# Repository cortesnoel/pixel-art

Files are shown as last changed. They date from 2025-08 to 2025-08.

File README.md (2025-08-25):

<h1 align="center" color="blue">
  <br>
  Pixel Art
  <br>
</h1>

<h4 align="center">Learn AI and game programming at the edge.</h4>

<p align="center">
  <a href="#key-features">Key Features</a> •
  <a href="#what-is-pixel-art">What is Pixel Art</a> •
  <a href="#why-pixel-art">Why Pixel Art</a> •
  <a href="#how-to-use">How to use</a> •
  <a href="#how-pixel-art-works">How Pixel Art Works</a> •
  <a href="#tutorials">Tutorials</a> •
  <a href="#community-plugins">Community Plugins</a> •
  <a href="#contributions">Contributions</a> •
  <a href="#license">License</a>
</p>

<p align="center">
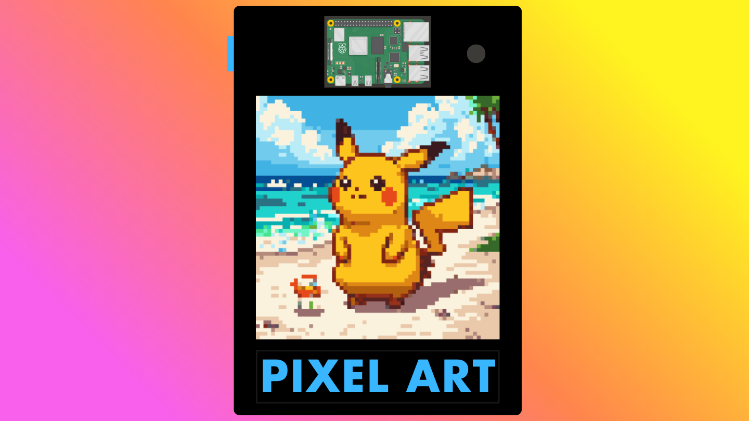
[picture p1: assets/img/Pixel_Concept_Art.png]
Markdownify
  
</p>

## Key Features

### Hardware

- edge platform using Raspberry Pi 4
- base build with opt-in components
- very minimal soldering
- customizable case design

### Software

- extendable through RGB, AI, game plugins
- support for RGB plugin development using [rpi-rgb-led-matrix](https://github.com/hzeller/rpi-rgb-led-matrix)
- support for AI plugin development using [Picovoice](https://picovoice.ai)
- support for game plugin development using [Pygame](https://www.pygame.org/wiki/GettingStarted)
- many plugin examples for RGB, AI, and games, ranging from simple to complex
- flexible plugin architecture so you can:
  - build custom plugins using other libraries or APIs (ex. OpenAI)
  - pair RGB with AI or game plugins in one-to-one, one-to-many, or many-to-many relationships
- built-in support for AI plugin audio and image modalities

## What is Pixel Art?

Pixel Art is a fun edge device for learning AI application and game development.
It provides a friendly environment for developers to create their own apps and games through plugins, then transfer those apps, or even integrate some or all of Pixel Art itself, into their own edge projects.

Pixel Art includes a 64x64 LED screen display, microphone, and optional speaker to support image and audio modalities.
Using Raspberry Pi 4 as it's main compute, it can support game development using smaller footprint libraries like Pygame.
It can also support small AI model inferencing locally or API requests to externally-hosted AI models.

The design is opensource under the [MIT](LICENSE) license so developers can customize Pixel Art towards their own learning goals by adding new hardware components, modifying the 3D prints, or creating custom software plugins.

## Why Pixel Art?

Studying various tech over the past several years, I found that developing on a personal or cloud compute often dulls the experience of learning new tech.
In many ways I felt disconnected from the tech I was learning.
The more I learned, the more it all transformed into an obscure blob within a "projects" or "study" folder.

I wanted a platform that made learning more engaging and personalized towards my own learning goals.

This is why I created Pixel Art, for software developers like me who also want to see their learning experience and apps come to life.
A complete learning platform with an open design that can be personalized towards individual learning goals and app deployments.

For education, this means a fun and refreshing development platform that can adapt to new projects and explorations.

If you're also looking to personalize your learning experience, further connect with the apps you're developing, or just really like pixel art, give it a try!

## How to use?

To use Pixel art you'll need to build the device, install the main software, then run existing plugins or create your own.

### Build Device

Visit [hardware](hardware) for a complete hardware build guide.

### Installation and Setup

Now that you have at least a base build of Pixel Art, you are ready to install and setup the main software.

1. Create any required model provider API keys.
For example, the initial configuration of Pixel Art requires a Picovoice API key which you can create with a [free account](https://picovoice.ai/pricing/#compare-our-plans).
Other paid model providers like [Retro Diffusion](https://www.retrodiffusion.ai) and [OpenAI](https://auth.openai.com/create-account) provide API keys which are good to have ready during this setup process, as some plugins require them.

2. ssh into your Pixel Art's raspberry pi using your [password](hardware/README.md#build-steps).

```bash
ssh rpi@pixel.local
```

3. Update the OS and install `git`.

```bash
sudo apt-get update && sudo apt-get install git -y
```

4. Clone this repo into your Pixel Art's `/opt` directory.

```bash
cd /opt && sudo git clone https://github.com/cortesnoel/pixel-art.git
```

5. Run [setup.sh](setup.sh) and follow any of its prompts. This may take a few minutes.

```bash
cd /opt/pixel-art && sudo chmod +x setup.sh && sudo ./setup.sh
```

6. Pixel Art will reboot once `setup.sh` completes.

### Run Existing Plugins

Upon reboot, Pixel Art should begin with the [display_heart_rand](plugins/rgb/random_pixel#display_heart_rand) RGB plugin
and [rd_wake](plugins/ai/retro_diffusion#rd_wake) AI plugin.

Make sure you have a Picovoice API key set as the environment variable `PICOVOICE_TOKEN`.
Pixel Art will fail to run the `rd_wake` plugin without it.

To test different plugins:

1. read the plugin's `README.md` to verify your Pixel Art device meets plugin requirements
1. list only your selected plugins in the [config.toml](config.toml)
1. reboot Pixel Art after any change to the [config.toml](config.toml)

**Note**: Given each plugin may have its own unique [event](#plugin-events) and [data](#passing-data-between-plugins) requirements, not every RGB plugin will be compatible with every AI or game plugin. Read each plugin's docs to know which can be paired together.

### Create Your First Plugin

Visit [Pixel Art Plugin Starter](https://github.com/cortesnoel/pixel-art-plugin-starter) for a complete guide on creating your first RGB, AI, or game plugin.

Also review existing [plugins](plugins) for examples.

## How Pixel Art Works?

### Plugin Events

Pixel Art runs two concurrent pipelines in a continuous loop, one to execute RGB plugins and the other for AI and game plugins. Both AI and game plugins can be thought of generally as "task" plugins.
Plugins are assigned to each of these pipelines in the [config.toml](config.toml) and follow the order they are listed in that file.

These pipelines orchestrate the timing of plugin execution through the use of plugin decorators `@RGBEvents()`, `@PicoEvents()`, and others that control the corresponding thread events. For example, the plugin decorators listed previously are meant to pair one RGB plugin to one task plugin (one-to-one relationship).

Generally, the event flow for a one-to-one plugin relationship is as follows:

1. AI plugin waits
1. RGB plugin starts
1. AI plugin starts
1. AI plugin ends
1. RGB plugin ends

If you instead want to pair one RGB plugin to two task plugins (one-to-many relationship), you would list in the [config.toml](config.toml) one RGB plugin that uses the `@RGBEvents()` plugin decorator and two task plugins that use the `@PicoEventStart()` and `@PicoEventEnd()` plugin decorators, respectively.

For game plugins, the `@AIGame()` plugin decorator also embeds the `@PicoEvents()` plugin decorator and so follows the same event handling.

### Plugin Decorators

There are many more plugin decorators to help you with quickly writing plugins, such as `@PicoModels()` which let's you quickly initialize Picovoice AI models for use within your AI or game plugin. For more info on plugin decorator use and their definitions, review the parent plugin modules and existing plugin examples in [plugins](plugins).

### Passing Data Between Plugins

Data can be passed between plugins in two ways:

1. AI -> AI: An AI plugin can pass data to the next AI plugin through its `return` statement. Depending on the number of values returned, the second AI plugin must accept the same number of parameters and match parameter names listed in the [ai_hook](plugin_manager/hook_spec.py) hookspec.

1. AI -> RGB: An AI plugin can pass data to its paired RGB plugin by sending it through the `ai_result_queue`. The RGB plugin must read this queue to get the data.

## Tutorials

*TBD*

## Community Plugins

**Note**: Always review and verify community plugins for errors and vulnerabilities prior to install or use.

*TBD*

## Contributions

### Core

Safety, security, and bug fix contributions are welcome for both Pixel Art hardware and software.

First open an issue containing a general description and potential solution. This allows for triage of issues with maintainer(s) prior to any PR, to verify work aligns with the direction of Pixel Art.

### Plugins

Plugin contributions are welcome and encouraged. Open an issue or PR for the plugin(s) you would like to contribute.

Robust plugins with popular features may be added to Pixel Art [plugins](plugins) directly. To keep the `plugins` directory from growing too large over time, alternatively your plugin can be referenced as an external repo in the [Community Plugins](#community-plugins) section.

## License

[MIT](LICENSE)

---

> LinkedIn [Noel Cortes](https://www.linkedin.com/in/noel-cortes-00ab8b181/)
&nbsp;&middot;&nbsp;
> Instagram [@noelcortes.libre](https://www.instagram.com/noelcortes.libre/)

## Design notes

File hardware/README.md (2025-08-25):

<h1 align="center" color="blue">
  <br>
  Hardware Build Guide
  <br>
</h1>

<p align="center">
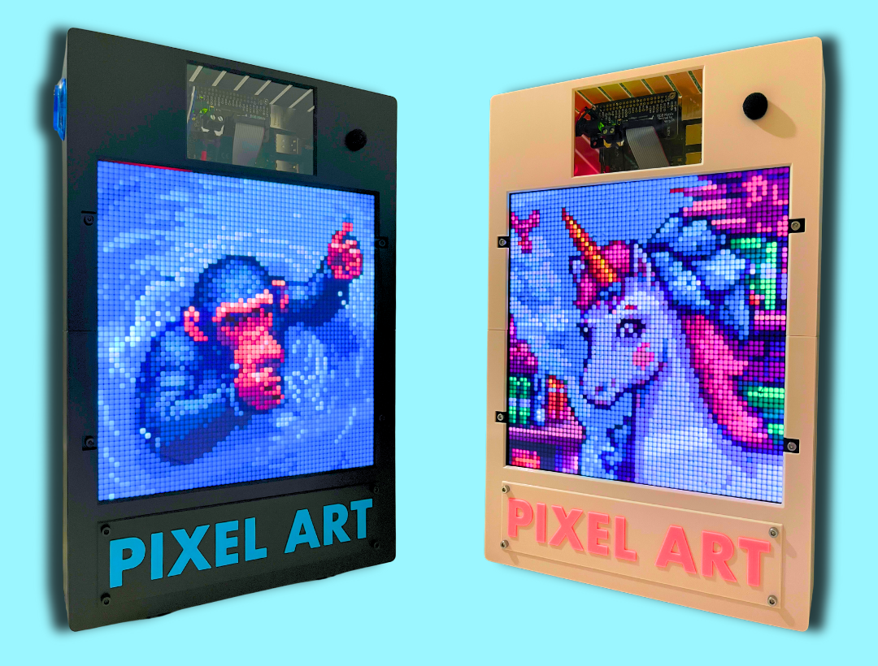
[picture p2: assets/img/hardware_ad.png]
Pixel Art Advertisement
  
</p>

## Parts

Welcome! To begin, buy all the [parts](BOM.md) for a Pixel Art base build, including for any additional features (ex. game controller).

## Build steps

1. Setup Raspberry Pi by following the official guide [Install an operating system](https://www.raspberrypi.com/documentation/computers/getting-started.html#installing-the-operating-system).
    - Install the Raspberry Pi OS Lite (64-bit)
    - Set your Wi-Fi credentials
    - Enable SSH and save password for later use

1. 3D print all [3mf files](prints) for the Pixel Art case (also the RGB matrix spacer not shown here).
   Tested on a Bambu Lab X1C 3D printer.
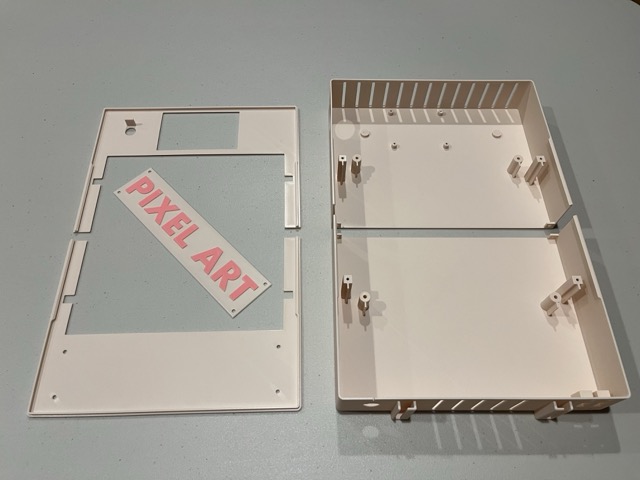
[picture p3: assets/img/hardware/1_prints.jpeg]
Prints
    <br><br>

1. Prepare RGB Bonnet by soldering necessary pins.
    - Solder a jumper wire between `GPIO4` and `GPIO18`
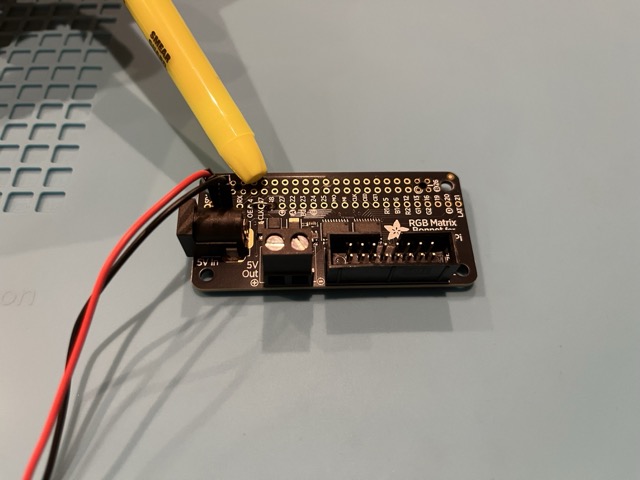
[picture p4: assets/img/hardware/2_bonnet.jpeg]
Bonnet jumper wire
    <br><br>
    - Melt a blob of solder on the bottom solder jumper so the middle pad is "shorted" to `8`
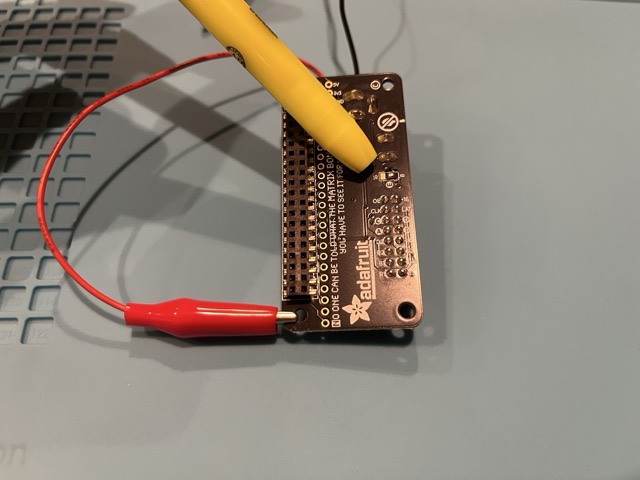
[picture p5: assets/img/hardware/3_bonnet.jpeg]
Bonnet solder pad
    <br><br>
    - Optional [ Button ]: Solder alligator clip wires to `SCL` and `GND`
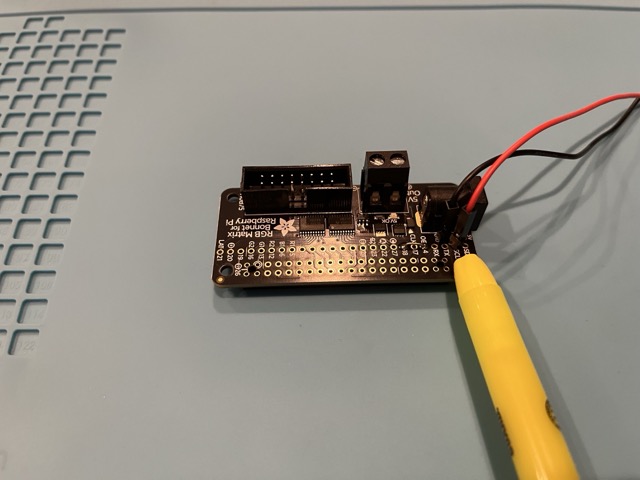
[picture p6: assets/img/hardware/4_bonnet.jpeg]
Bonnet button pins
    <br><br>

1. Connect RGB Bonnet to Raspberry Pi 4 using 2x20 pin riser header.
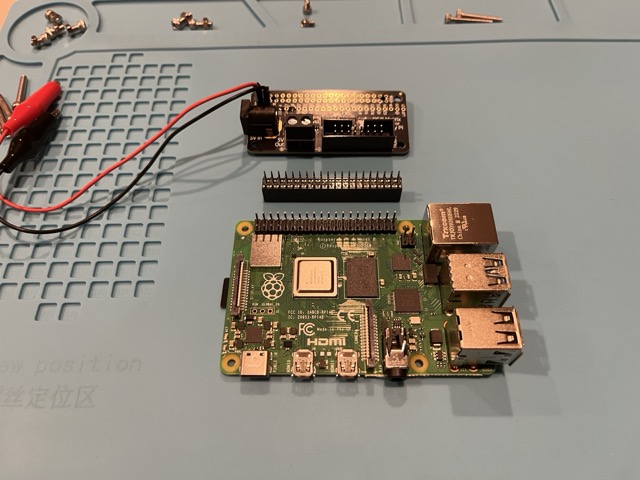
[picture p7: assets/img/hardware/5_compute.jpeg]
RPI and Bonnet stack
<br>
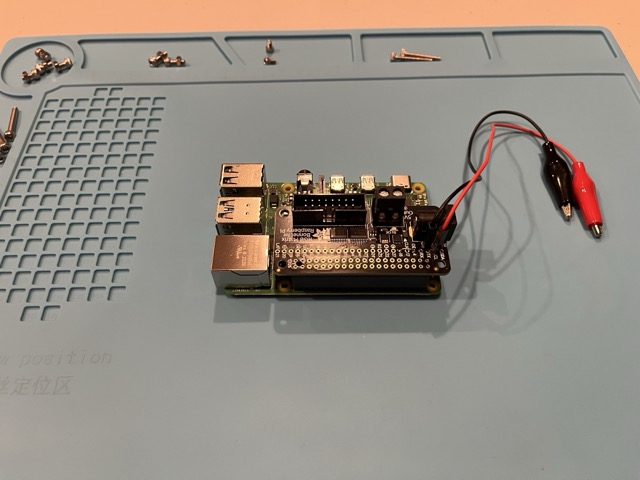
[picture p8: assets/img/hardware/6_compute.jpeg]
RPI and Bonnet stack alt
<br><br>

1. Tape top and bottom case together to keep the case steady.
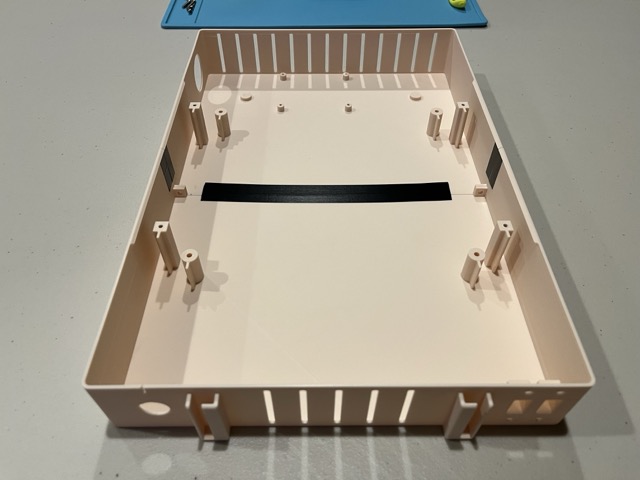
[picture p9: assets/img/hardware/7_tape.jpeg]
Tape case
<br><br>

1. Screw top and bottom case together with 2 x M3x8mm screws and nuts.
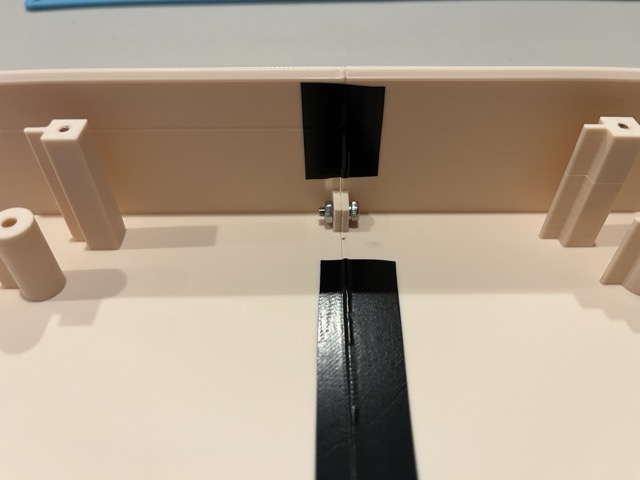
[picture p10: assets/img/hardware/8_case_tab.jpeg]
Screw case tab
<br><br>

1. Screw Raspberry Pi onto case with 2 x M2.5x4mm and 2 x M2.5x20mm.
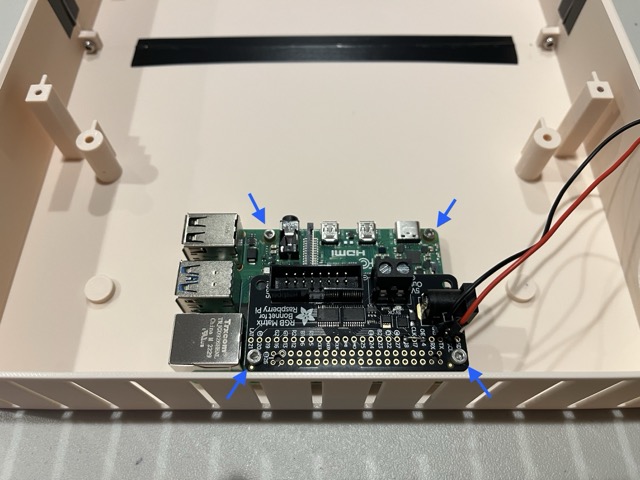
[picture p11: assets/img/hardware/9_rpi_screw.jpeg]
Screw in RPI
<br><br>

1. Optional [ Panel Mount USB ]: Screw in USB panel mounts and plug into Raspberry Pi USB 2.0 ports.
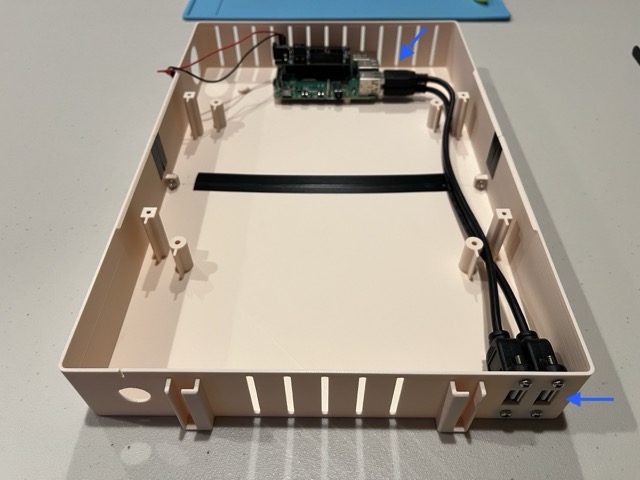
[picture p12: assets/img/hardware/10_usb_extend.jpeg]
Panel mounts
<br><br>

1. Plug in power cables by feeding cables through the case's power cable hole (hole printed with slit if needed to cut open).
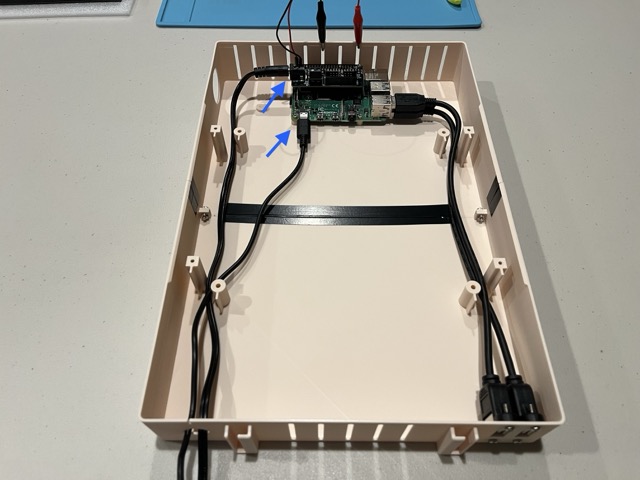
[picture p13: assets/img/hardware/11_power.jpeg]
Power cables
<br><br>

1. Optional [ Button ]: Attach button to case and attach RGB Bonnet alligator clips to button.
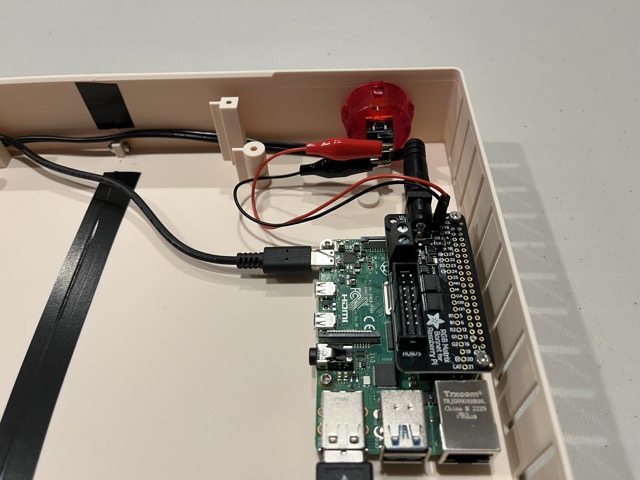
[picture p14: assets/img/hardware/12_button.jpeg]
Button connection
<br><br>

1. Attach RGB matrix by aligning matrix screw holes with the four circle stands in case. Screw in from back of the case using 4 x M3x12mm screws.
*Warning*: Treat RGB matrix as fragile or else you risk permanently damaging the LEDs.
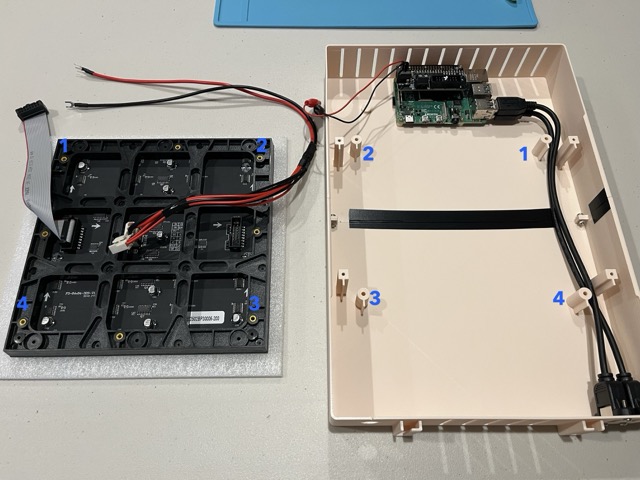
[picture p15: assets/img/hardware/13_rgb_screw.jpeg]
Screw in RGB matrix
<br><br>

1. Connect RGB matrix data and power cables to the RGB Bonnet.
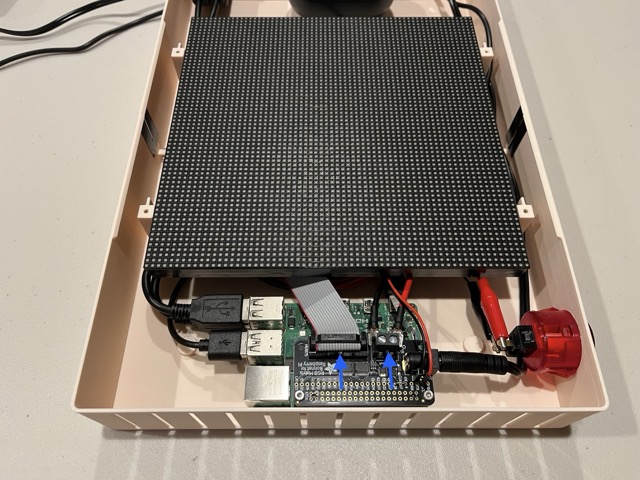
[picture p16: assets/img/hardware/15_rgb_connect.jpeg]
RGB matrix data and power
<br><br>

1. Connect speaker to Raspberry Pi USB 3.0 port. If keeping speaker inside the case, use an adhesive to keep from moving and potentially damaging the RGB LED matrix.
Alternatively, you can plugin from outside the case if Panel Mount USB is installed.
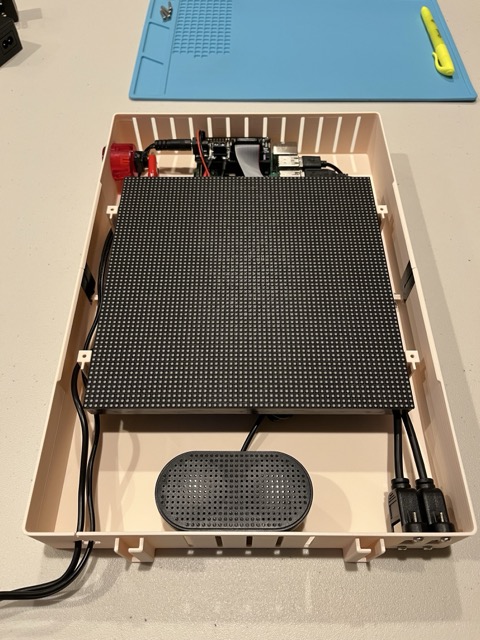
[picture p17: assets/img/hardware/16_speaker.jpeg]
Speaker
<br><br>

1. Cut your RGB diffuser acrylic to size 195mm x 214mm. Cut your Raspberry Pi clear acrylic to size 60mm x 94mm. You can use an acrylic scoring tool to cut sizes.
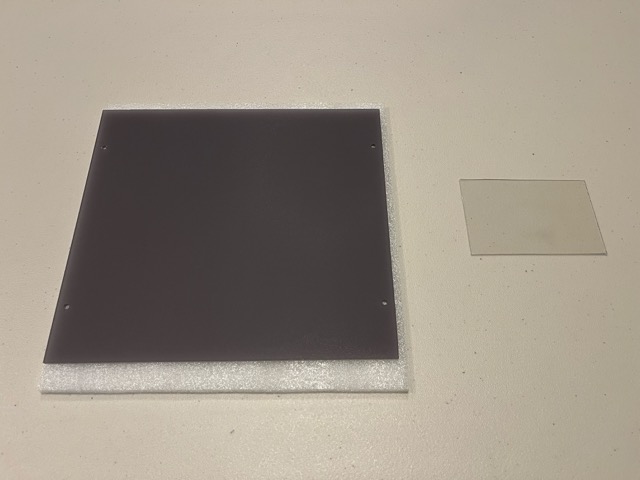
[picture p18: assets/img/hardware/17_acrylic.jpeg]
Acrylic dimensions
<br><br>

1. Drill 1/8in holes into RGB diffuser acrylic using the RGB matrix spacer's print holes as guides, this way holes align exactly.
*Warning*: Drill slow and work up drill bit sizes to avoid chipping or cracking acrylic's edge.
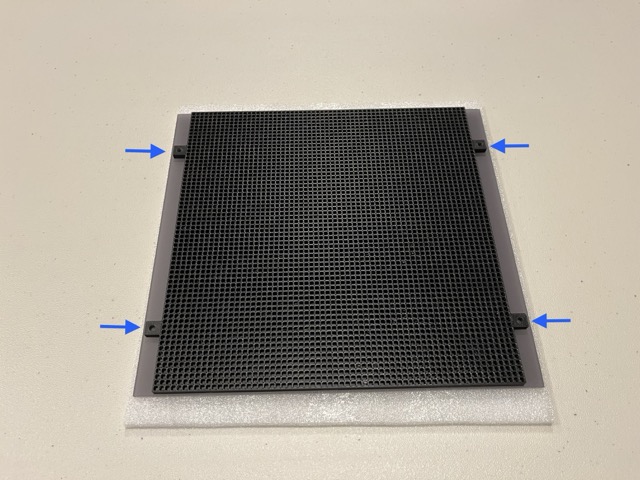
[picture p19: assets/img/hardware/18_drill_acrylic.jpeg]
Acrylic drill holes
<br><br>

1. Stack the RGB matrix spacer, then RGB diffuser acrylic (rough side down), onto the RGB matrix.
   Align holes with the case's square stands and screw into the case using 4 x M3x20mm screws.
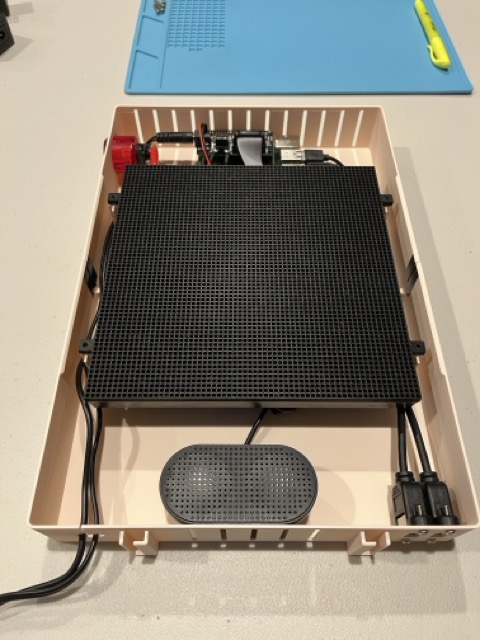
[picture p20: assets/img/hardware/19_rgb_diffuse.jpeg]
Stack screen
<br>
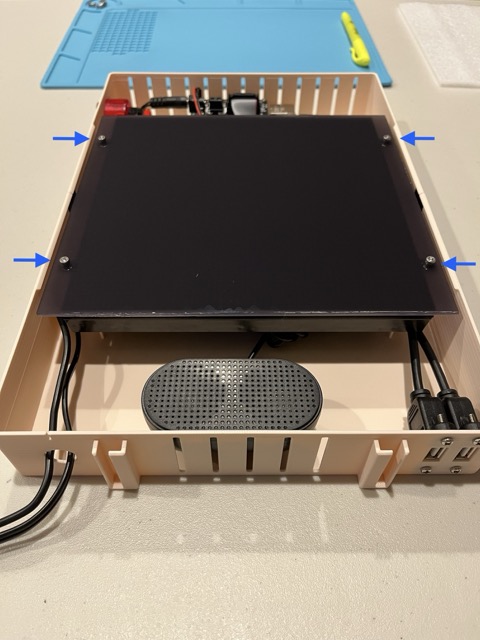
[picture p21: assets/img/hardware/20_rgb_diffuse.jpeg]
Screw screen
<br>

1. Tape or glue clear acrylic to top cover.
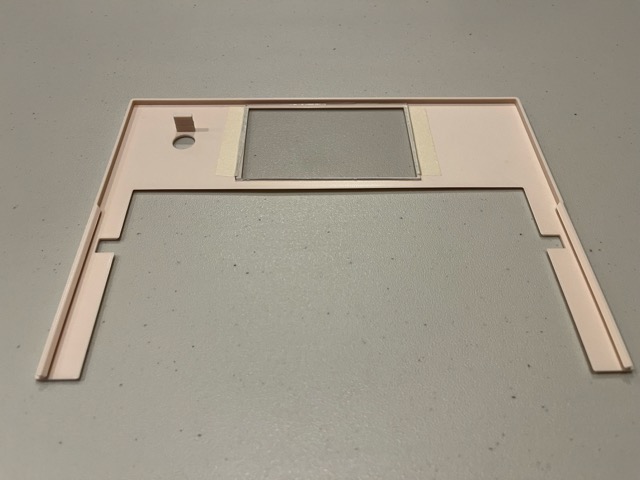
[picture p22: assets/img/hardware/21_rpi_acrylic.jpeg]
Tape RPI acrylic
<br><br>

1. Screw nameplate onto bottom cover using 4 x M3x6mm screws and nuts.
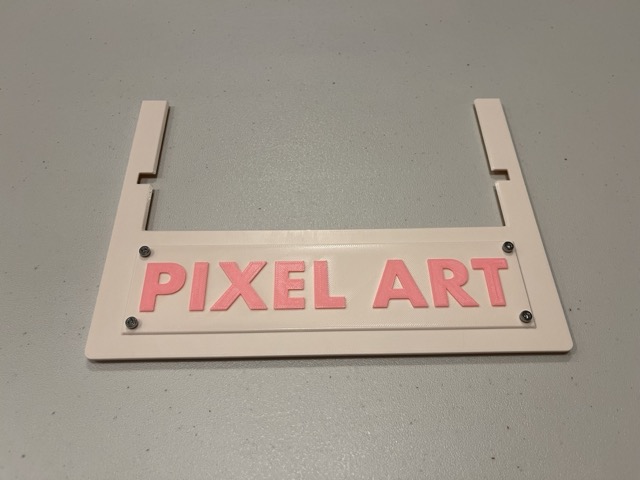
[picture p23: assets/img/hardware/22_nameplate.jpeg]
Screw nameplate
<br><br>

1. Plug in microphone to Raspberry Pi USB 3.0 port and clip onto top cover's microphone tab.
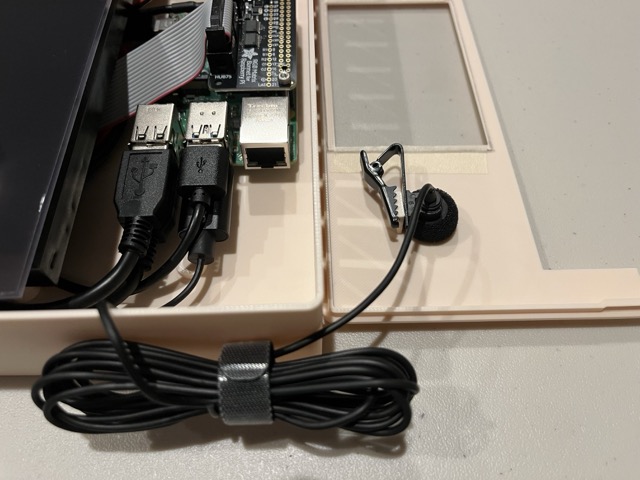
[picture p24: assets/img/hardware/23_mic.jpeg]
Connect microphone
<br><br>

1. Snap on top and bottom cover.
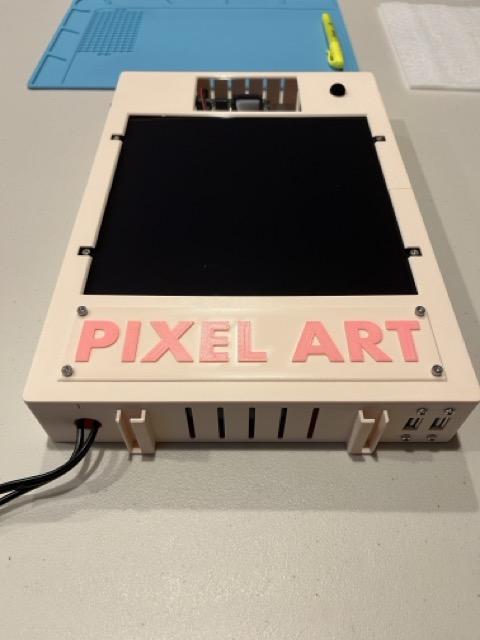
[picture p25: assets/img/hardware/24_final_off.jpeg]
Snap on cover
<br><br>

1. Power on Pixel Art!
Below is an example of an image generated by [Retro Diffusion Plugins](../plugins/ai/retro_diffusion/README.md).
<br>Pixel Art powered on<br>

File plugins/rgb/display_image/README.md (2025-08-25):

<h1 align="center">Display Image</h1>
<br>
<p align="center">RGB Plugin to display images, GIFs, gameplay, and an emoting avatar on the Pixel Art screen.</p>

<br>
<p align="center">
  
  
  gameplay
  
</p>

## Requirements

Basic build of Pixel Art.

Reference your chosen AI or game plugin(s) for additional requirements.

## Plugins

1. [display_image](#display_image)
1. [display_gif](#display_gif)
1. [display_game](#display_game)
1. [display_emotion_avatar](#display_emotion_avatar)

---

### `display_image`

Display an image on the Pixel Art screen.

#### Usage

Pair with an AI plugin that sends a local image path to this plugin using `ai_result_queue`.

```python
self.ai_result_queue.put("path/to/image.png")
```

For example, pair with the Retro Diffusion [rd_text_to_image](../../ai/retro_diffusion/README.md#rd_text_to_image) AI plugin.

##### Steps

1. Set in Pixel Art's [config.toml](../../../config.toml):
```toml
[plugins]

ai = [
  # retro diffusion
  "retro_diffusion_plugins.RetroDiffusionPlugins.rd_wake",
  "retro_diffusion_plugins.RetroDiffusionPlugins.rd_speech_to_text",
  "retro_diffusion_plugins.RetroDiffusionPlugins.rd_text_to_image"
]

rgb = [
  # retro diffusion
  "random_pixel_plugins.RandomPixelPlugins.display_heart_rand",
  "random_pixel_plugins.RandomPixelPlugins.display_snake_rand",
  "display_image_plugins.DisplayImagePlugins.display_image" # this plugin
]
```
2. Launch or restart Pixel Art
3. `rd_wake`: Say "Hey Pixel Art!"
4. `rd_speech_to_text`: Describe the image you want generated
5. `rd_text_to_image`: Wait for image to display on the Pixel Art screen

#### Examples

<p align="left">
  
  
  
</p>

---

### `display_gif`

Display a GIF on the Pixel Art screen.

#### Usage

Pair with an AI plugin that sends a local GIF path to this plugin using `ai_result_queue`.

```python
self.ai_result_queue.put("path/to/image.gif")
```

##### Steps

1. Set in Pixel Art's [config.toml](../../../config.toml):
```toml
[plugins]

ai = [
  "<your custom AI plugin>"
]

rgb = [
  "display_image_plugins.DisplayImagePlugins.display_gif" # this plugin
]
```
2. Launch or restart Pixel Art
3. ...

**Examples**



---

### `display_game`

Display gameplay on the Pixel Art screen.

#### Usage

Pair with a game plugin that sends a gameplay frame as an image to this plugin. This is automatically done for you when using the [GamePlugin](../../game_plugin.py) `draw()` method.

```python
self.draw()
```

For example, pair with the [Basic](../../game/basic/README.md) game plugin.

##### Steps

1. Set in Pixel Art's [config.toml](../../../config.toml):
```toml
[plugins]

ai = [
  # basic game
  "basic.BasicGame.play"
]

rgb = [
  # basic game
  "display_image_plugins.DisplayImagePlugins.display_game" # this plugin
]
```
2. Launch or restart Pixel Art
3. `main`: Play your game

**Examples**

gameplay

---

### `display_emotion_avatar`

Display an emoting avatar on the Pixel Art screen. 

#### Usage

Pair with an AI plugin that continuously sends an emotion and display time (in seconds) to this plugin using `ai_result_queue`.

```python
self.ai_result_queue.put(("joy", 10))
```

For example, pair with the OpenAI Assistant [assistant_run](../../ai/openai_assistant/README.md#assistant_run) AI plugin.

##### Steps

1. Set in Pixel Art's [config.toml](../../../config.toml):
```toml
[plugins]

ai = [
  # openai assistant
  "openai_assistant.OpenAI_Assistant_Plugin.assistant_wake",
  "openai_assistant.OpenAI_Assistant_Plugin.run"
]

rgb = [
  # openai assistant
  "random_pixel_plugins.RandomPixelPlugins.display_smiley_rand",
  "display_image_plugins.DisplayImagePlugins.display_emotion_avatar" # this plugin
]
```
2. Launch or restart Pixel Art
3. `assistant_wake`: Say "Hey Pixel Art!"
4. `run`: Conversate with OpenAI Assistant and view emotive GIFs on screen

#### Examples

<p align="left">
  
  
  
  
  
   
</p>

---

## Configuration

Plugin configurations can be set in [plugin.toml](plugin.toml).

## Troubleshoot

TBD

## License

[MIT](LICENSE)

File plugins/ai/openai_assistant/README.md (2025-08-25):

<h1 align="center">OpenAI Assistant</h1>
<br>
<p align="center">
  The Pixel Art voice chatbot powered by OpenAI's <a href="https://platform.openai.com/docs/guides/realtime">Realtime API</a>.
</p>
<p align="center">
  Currently doesn't support any tool calling and is limited by the AI model's <a href="https://platform.openai.com/docs/models/gpt-4o-realtime-preview">knowledge cutoff</a> date.
</p>
<br>

## Examples

Example AI responses can be downloaded from [assets/examples](assets/examples).

## Requirements

### Hardware

The following Pixel Art I/O hardware is required to support this plugin: `microphone`, `speaker`.

### API Keys

The following API keys must be set as system environment variables:

- [Picovoice](https://console.picovoice.ai/signup#free): `PICOVOICE_TOKEN`
- [OpenAI](https://platform.openai.com/api-keys): `OPENAI_API_KEY`

## Plugins

1. [assistant_wake](#assistant_wake)
1. [assistant_run](#assistant_run)

---

### `assistant_wake`

Listens for the wake phrase "Hey Pixel Art." Once the wake phrase is detected, this plugin exits.

#### Modalities

- **in**: audio
- **out**: none

#### Usage

Pair with an RGB plugin that expects no values from the `ai_result_queue`.

For example, pair with the Random Pixel [display_heart_rand](../../rgb/random_pixel/README.md#display_heart_rand) RGB plugin.

##### Steps

1. Set in Pixel Art's [config.toml](../../../config.toml):
```toml
[plugins]

ai = [
  # openai assistant
  "openai_assistant.OpenAIAssistantPlugins.assistant_wake" # this plugin
]

rgb = [
  # openai assistant
  "random_pixel_plugins.RandomPixelPlugins.display_heart_rand"
]
```
2. Launch or restart Pixel Art
3. `assistant_wake`: Say "Hey Pixel Art!"

---

### `assistant_run`

A voice chatbot that follows a natural conversation flow.

#### Modalities

- **in**: audio
- **out**: audio

#### Usage

Once the plugin starts, the OpenAI Assistant will greet you first and then follows a natural conversation flow.
It disables the mic when responding and enables it again once finished.

Highly recommend to pair the Assistant's `assistant_run` plugin with the RGB plugin [display_emotion_avatar](../../rgb/display_image/README.md#display_emotion_avatar).
This RGB plugin listens for the emotion classification of each Assistant response and chooses the appropriate emoting gif (joy, sadness, etc.).
Additionally, the avatar's eyes will be `white` when listening/speaking and `light blue` when thinking/processing.

##### Steps

1. Set in Pixel Art's [config.toml](../../../config.toml):
```toml
[plugins]

ai = [
  # openai assistant
  "openai_assistant.OpenAIAssistantPlugins.assistant_wake",
  "openai_assistant.OpenAIAssistantPlugins.assistant_run" # this plugin
]

rgb = [
  # openai assistant
  "random_pixel_plugins.RandomPixelPlugins.display_heart_rand",
  "display_image_plugins.DisplayImagePlugins.display_emotion_avatar"
]
```
2. Launch or restart Pixel Art
3. `assistant_wake`: Say "Hey Pixel Art!"
4. `assistant_run`: Chat with the OpenAI Assistant

---

## Configuration

Plugin configurations can be set in [plugin.toml](plugin.toml).

## Troubleshoot

TBD

## License

[MIT](LICENSE)

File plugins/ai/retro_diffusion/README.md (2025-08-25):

<h1 align="center">Retro Diffusion</h1>
<br>
<p align="center">
  AI Plugin to generate images using <a href="https://www.retrodiffusion.ai">Retro Diffusion</a>.
</p>

<br>
<p align="center">
  
  
  
  
  
</p>

## Requirements

### Hardware

The following Pixel Art I/O hardware is required to support this plugin: `microphone`, `speaker`.

### API Keys

The following API keys must be set as system environment variables:

- [Picovoice](https://console.picovoice.ai/signup#free): `PICOVOICE_TOKEN`
- [Retro Diffusion](https://www.retrodiffusion.ai): `RETRO_DIFFUSION_TOKEN`

## Plugins

1. [rd_wake](#rd_wake)
1. [rd_speech_to_text](#rd_speech_to_text)
1. [rd_text_to_image](#rd_text_to_image)

---

### `rd_wake`

Listens for the wake phrase "Hey Pixel Art." Once the wake phrase is detected, this plugin exits.

#### Modalities

- **in**: audio
- **out**: none

#### Usage

Pair with an RGB plugin that expects no values from the `ai_result_queue`.

For example, pair with the Random Pixel [display_smiley_rand](../../rgb/random_pixel/README.md#display_smiley_rand) RGB plugin.

##### Steps

1. Set in Pixel Art's [config.toml](../../../config.toml):
```toml
[plugins]

ai = [
  # retro diffusion
  "retro_diffusion_plugins.RetroDiffusionPlugins.rd_wake" # this plugin
]

rgb = [
  # retro diffusion
  "random_pixel_plugins.RandomPixelPlugins.display_smiley_rand"
]
```
2. Launch or restart Pixel Art
3. `rd_wake`: Say "Hey Pixel Art!"

---

### `rd_speech_to_text`

Records speech for a configurable amount of time and then transcribes the speech.
Transcribed speech is then forwarded as a string value to the next AI plugin.

#### Modalities

- **in**: audio
- **out**: text

#### Usage

Pair with an RGB plugin that expects no values from the `ai_result_queue`.

For example, pair with the Fill Screen [display_strobe_fill](../../rgb/fill_screen/README.md#display_strobe_fill) RGB plugin.

##### Steps

1. Set in Pixel Art's [config.toml](../../../config.toml):
```toml
[plugins]

ai = [
  # retro diffusion
  "retro_diffusion_plugins.RetroDiffusionPlugins.rd_wake",
  "retro_diffusion_plugins.RetroDiffusionPlugins.rd_speech_to_text" # this plugin
]

rgb = [
  # retro diffusion
  "random_pixel_plugins.RandomPixelPlugins.display_smiley_rand",
  "fill_screen_plugins.FillScreenPlugins.display_strobe_fill"
]
```
2. Launch or restart Pixel Art
3. `rd_wake`: Say "Hey Pixel Art!"
4. `rd_speech_to_text`: Describe to Pixel Art the image you would like to create

---

### `rd_text_to_image`

Generates a new image from a description text using [Retro Diffusion AI](https://www.retrodiffusion.ai).
The image description is a string value returned by the AI plugin that was executed previous to this plugin.

For example, set [rd_speech_to_text](#rd_speech_to_text) previous to this plugin in the AI plugin pipeline.
It will record your speech and return its transcription. Then this plugin will use the transcription as the
image description for generating a new image.

#### Modalities

- **in**: text
- **out**: image

#### Usage

Pair with an RGB plugin that expects an image path value from the `ai_result_queue`.

For example, pair with the Display Image [display_image](../../rgb/display_image/README.md#display_image) RGB plugin.

##### Steps

1. Set in Pixel Art's [config.toml](../../../config.toml):
```toml
[plugins]

ai = [
  # retro diffusion
  "retro_diffusion_plugins.RetroDiffusionPlugins.rd_wake",
  "retro_diffusion_plugins.RetroDiffusionPlugins.rd_speech_to_text",
  "retro_diffusion_plugins.RetroDiffusionPlugins.rd_text_to_image" # this plugin
]

rgb = [
  # retro diffusion
  "random_pixel_plugins.RandomPixelPlugins.display_smiley_rand",
  "fill_screen_plugins.FillScreenPlugins.display_strobe_fill",
  "display_image_plugins.DisplayImagePlugins.display_image"
]
```
2. Launch or restart Pixel Art
3. `rd_wake`: Say "Hey Pixel Art!"
4. `rd_speech_to_text`: Describe to Pixel Art the image you would like to create
5. `rd_text_to_image`: Generates new image from the description
6. See new image on the Pixel Art screen

#### Examples

<p align="left">
  
  
  
  
  
</p>

---

## Configuration

Plugin configurations can be set in [plugin.toml](plugin.toml).

## Troubleshoot

TBD

## License

[MIT](LICENSE)

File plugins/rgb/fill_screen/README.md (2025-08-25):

<h1 align="center">Random Pixel</h1>
<br>
<p align="center">RGB Plugin to display fullscreen patterns on the Pixel Art screen.</p>

<br>
<p align="center">
  
  
</p>

## Requirements

Basic build of Pixel Art.

Reference your chosen AI or game plugin(s) for additional requirements.

## Plugins

1. [display_strobe_fill](#display_strobe_fill)
1. [display_scatter_fill](#display_scatter_fill)

---

### `display_strobe_fill`

Display a strobe-like pattern on the Pixel Art screen.

#### Usage

Pair with an AI plugin meant for background tasks. This plugin doesn't use any value from the `ai_result_queue`.

For example, pair with the Retro Diffusion [rd_wake](../../ai/retro_diffusion/README.md#rd_wake) AI plugin.

##### Steps

1. Set in Pixel Art's [config.toml](../../../config.toml):
```toml
[plugins]

ai = [
  # retro diffusion
  "retro_diffusion_plugins.RetroDiffusionPlugins.rd_wake"
]

rgb = [
  # retro diffusion
  "fill_screen_plugins.FillScreenPlugins.display_strobe_fill" # this plugin
]
```
2. Launch or restart Pixel Art
3. View strobe pattern on screen
4. `rd_wake`: Say "Hey Pixel Art!"

#### Examples



---

### `display_scatter_fill`

Display a scattered multi-color pattern on the Pixel Art screen.

#### Usage

Pair with an AI plugin meant for background tasks. This plugin doesn't use any value from the `ai_result_queue`.

For example, pair with the Retro Diffusion [rd_wake](../../ai/retro_diffusion/README.md#rd_wake) AI plugin.

##### Steps

1. Set in Pixel Art's [config.toml](../../../config.toml):
```toml
[plugins]

ai = [
  # retro diffusion
  "retro_diffusion_plugins.RetroDiffusionPlugins.rd_wake"
]

rgb = [
  # retro diffusion
  "fill_screen_plugins.FillScreenPlugins.display_scatter_fill" # this plugin
]
```
2. Launch or restart Pixel Art
3. View scattered multi-color pattern on screen
4. `rd_wake`: Say "Hey Pixel Art!"

#### Examples



---

## Configuration

Plugin configurations can be set in [plugin.toml](plugin.toml).

## Troubleshoot

TBD

## License

[MIT](LICENSE)

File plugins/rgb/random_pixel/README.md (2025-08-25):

<h1 align="center">Random Pixel</h1>
<br>
<p align="center">RGB Plugin to display randomized patterns on the Pixel Art screen.</p>

<br>
<p align="center">
  
  
  
  
</p>

## Requirements

Basic build of Pixel Art.

Reference your chosen AI or game plugin(s) for additional requirements.

## Plugins

1. [display_pixel_rand](#display_pixel_rand)
1. [display_heart_rand](#display_heart_rand)
1. [display_smiley_rand](#display_smiley_rand)
1. [display_snake_rand](#display_snake_rand)

---

### `display_pixel_rand`

Display colored pixel(s) randomly on the Pixel Art screen.

#### Usage

Pair with an AI plugin meant for background tasks. This plugin doesn't use any value from the `ai_result_queue`.

For example, pair with the Retro Diffusion [rd_wake](../../ai/retro_diffusion/README.md#rd_wake) AI plugin.

##### Steps

1. Set in Pixel Art's [config.toml](../../../config.toml):
```toml
[plugins]

ai = [
  # retro diffusion
  "retro_diffusion_plugins.RetroDiffusionPlugins.rd_wake"
]

rgb = [
  # retro diffusion
  "random_pixel_plugins.RandomPixelPlugins.display_pixel_rand" # this plugin
]
```
2. Launch or restart Pixel Art
3. View random pixel(s) on screen
4. `rd_wake`: Say "Hey Pixel Art!"

#### Examples



---

### `display_heart_rand`

Display colored heart(s) randomly on the Pixel Art screen.

#### Usage

Pair with an AI plugin meant for background tasks. This plugin doesn't use any value from the `ai_result_queue`.

For example, pair with the Retro Diffusion [rd_wake](../../ai/retro_diffusion/README.md#rd_wake) AI plugin.

##### Steps

1. Set in Pixel Art's [config.toml](../../../config.toml):
```toml
[plugins]

ai = [
  # retro diffusion
  "retro_diffusion_plugins.RetroDiffusionPlugins.rd_wake"
]

rgb = [
  # retro diffusion
  "random_pixel_plugins.RandomPixelPlugins.display_heart_rand" # this plugin
]
```
2. Launch or restart Pixel Art
3. View random heart(s) on screen
4. `rd_wake`: Say "Hey Pixel Art!"

#### Examples



---

### `display_smiley_rand`

Display a smiley randomly on the Pixel Art screen.

#### Usage

Pair with an AI plugin meant for background tasks. This plugin doesn't use any value from the `ai_result_queue`.

For example, pair with the Retro Diffusion [rd_wake](../../ai/retro_diffusion/README.md#rd_wake) AI plugin.

##### Steps

1. Set in Pixel Art's [config.toml](../../../config.toml):
```toml
[plugins]

ai = [
  # retro diffusion
  "retro_diffusion_plugins.RetroDiffusionPlugins.rd_wake"
]

rgb = [
  # retro diffusion
  "random_pixel_plugins.RandomPixelPlugins.display_smiley_rand" # this plugin
]
```
2. Launch or restart Pixel Art
3. View random smiley on screen
4. `rd_wake`: Say "Hey Pixel Art!"

#### Examples



---

### `display_snake_rand`

Display colored pixel snake that grows as it moves randomly on the Pixel Art screen.

#### Usage

Pair with an AI plugin meant for background tasks. This plugin doesn't use any value from the `ai_result_queue`.

For example, pair with the Retro Diffusion [rd_wake](../../ai/retro_diffusion/README.md#rd_wake) AI plugin.

##### Steps

1. Set in Pixel Art's [config.toml](../../../config.toml):
```toml
[plugins]

ai = [
  # retro diffusion
  "retro_diffusion_plugins.RetroDiffusionPlugins.rd_wake"
]

rgb = [
  # retro diffusion
  "random_pixel_plugins.RandomPixelPlugins.display_snake_rand" # this plugin
]
```
2. Launch or restart Pixel Art
3. View pixel snake on screen
4. `rd_wake`: Say "Hey Pixel Art!"

#### Examples



---

## Configuration

Plugin configurations can be set in [plugin.toml](plugin.toml).

## Troubleshoot

TBD

## License

[MIT](LICENSE)

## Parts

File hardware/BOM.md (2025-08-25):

# BOM

Please review [Hardware Build Guide](README.md) to get an idea on part usage.

## Required - Base Build

### Adafruit

- [Raspberry Pi 4 Model B](https://www.adafruit.com/product/4564)
  - Higher RAM recommended for running small AI models locally
- [RGB Matrix Bonnet](https://www.adafruit.com/product/3211)
- [64x64 RGB LED Matrix - 3mm Pitch](https://www.adafruit.com/product/4732)
- [Black LED Diffusion Acrylic Panel 12" x 12" - 0.1"](https://www.adafruit.com/product/4594)
- [Mini External USB Stereo Speaker](https://www.adafruit.com/product/3369)
- [2x20 Socket Riser Header](https://www.adafruit.com/product/4079)
- [Raspberry Pi Power Supply](https://www.adafruit.com/product/4298)
- [5V 4A switching power supply](https://www.adafruit.com/product/1466)
  - *Note*: RGB LED Matrix draws approx. 3A of power so needs high-amp power supply

### Amazon

- [Micro SD Card](https://www.amazon.com/SanDisk-Extreme-microSDXC-Memory-Adapter/dp/B09X7BK27V?ref_=ast_sto_dp&th=1)
  - Raspberry Pi [supported cards](https://www.raspberrypi.com/documentation/accessories/sd-cards.html)
- [Saramonic SR-ULM10 Microphone](https://www.amazon.com/dp/B087CFY8K5?ref=ppx_yo2ov_dt_b_fed_asin_title&th=1)
- [M2.5 Screws](https://www.amazon.com/Pieces-Washers-Sutemribor-Assortment-Threaded/dp/B0CXQ4QTGT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)
- [M3 Screws](https://www.amazon.com/dp/B0B51BFSWZ?ref=ppx_yo2ov_dt_b_fed_asin_title&th=1)
- [Clear Plexiglass - 1mm](https://www.amazon.com/dp/B09Y2ZGRRB?ref=ppx_yo2ov_dt_b_fed_asin_title)

## Optional by Feature

### Case

- [5V Square USB Fan - 4 cm](https://www.adafruit.com/product/6101)
- 2 x [Panel Mount USB Cable - A Male to A Female](https://www.adafruit.com/product/908)
- [1/2in Braided Cable Sleeve](https://www.amazon.com/dp/B074LRSL3H?ref=ppx_yo2ov_dt_b_fed_asin_title&th=1)
- 1/2in rubber grommet

### Power Button

- [Arcade Button - 30mm](https://www.adafruit.com/product/476)
- [Small Alligator Clip to Male Jumper Wire](https://www.adafruit.com/product/3448)

### Gaming

- [USB Game Controller with SNES-like Layout](https://www.adafruit.com/product/6285)

# Tools

- Soldering iron with solder
- Plexiglass scoring knife
- Power drill
- Safety equipment

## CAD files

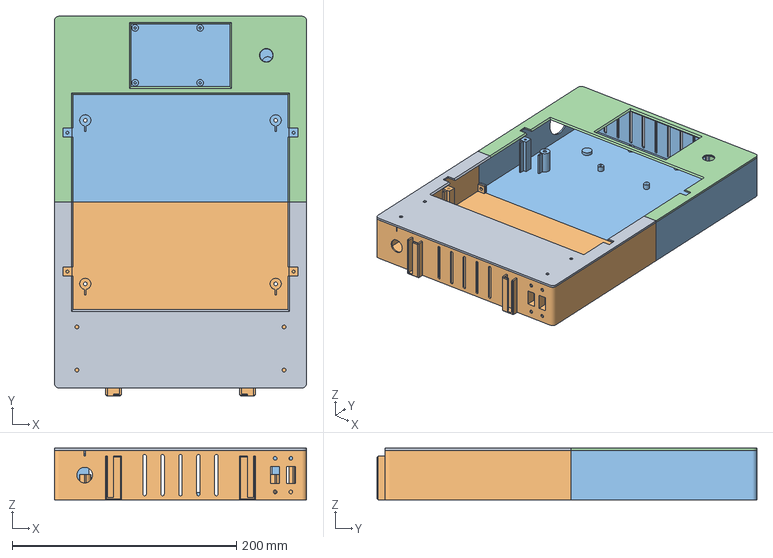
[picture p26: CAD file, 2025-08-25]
hardware/prints/Case_v1.3mf
225.0 x 339.0 x 46.0 mm
Bottom x 2
Top x 2

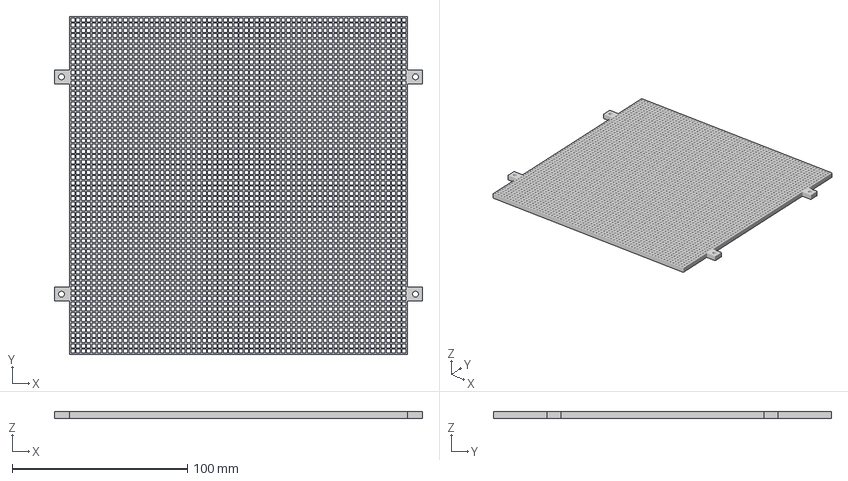
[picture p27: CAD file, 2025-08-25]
hardware/prints/Spacer_v1.3mf
210.0 x 192.8 x 4.00 mm

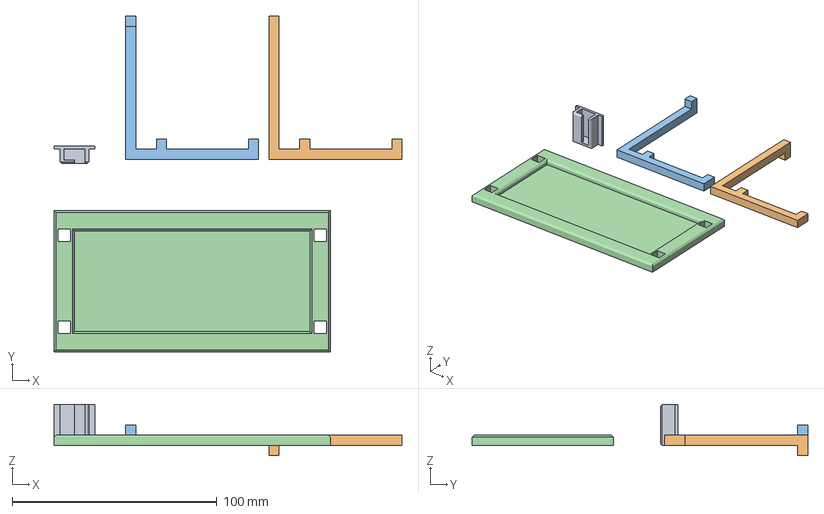
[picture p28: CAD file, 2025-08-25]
hardware/prints/Platform_v1.3mf
170.0 x 164.0 x 25.0 mm
Anchor Right
Hook Left
Hook Right
Platform

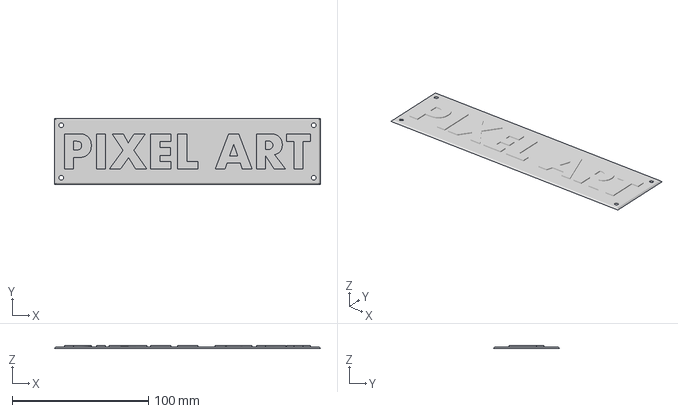
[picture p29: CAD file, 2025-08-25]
hardware/prints/Name_Plate_v1.3mf
195.0 x 48.5 x 2.00 mm

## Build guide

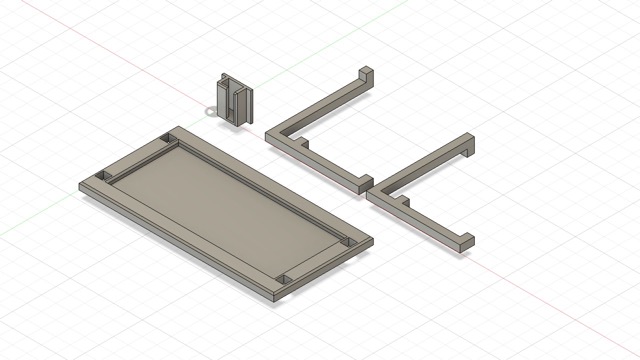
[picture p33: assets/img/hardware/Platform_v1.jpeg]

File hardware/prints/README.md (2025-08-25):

## Case

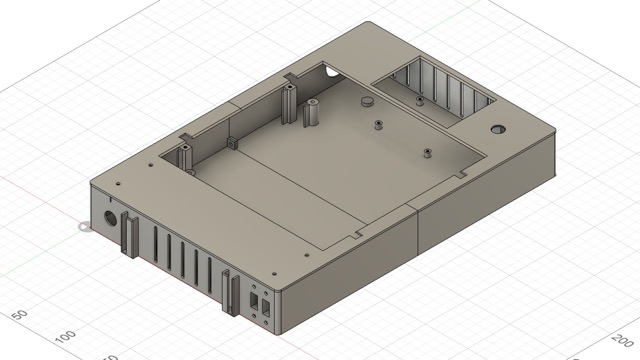
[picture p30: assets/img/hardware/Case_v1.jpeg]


## Spacer

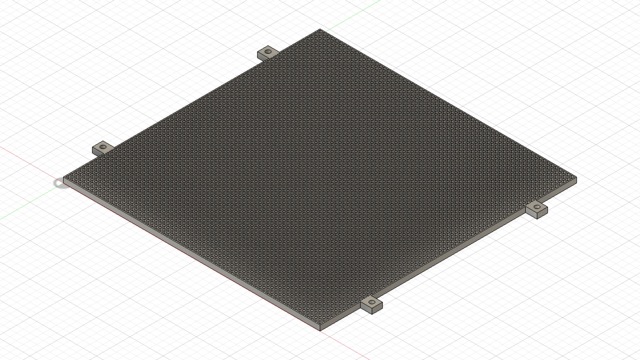
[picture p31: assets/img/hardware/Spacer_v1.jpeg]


## Name Plate

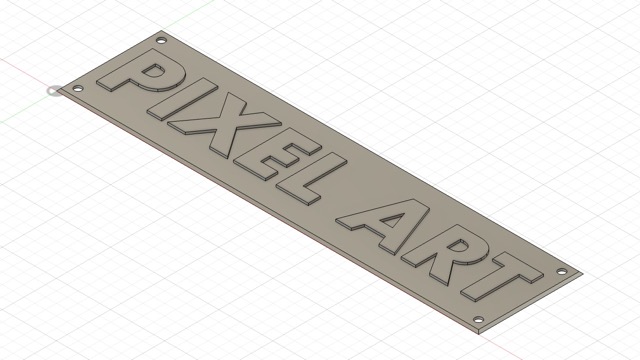
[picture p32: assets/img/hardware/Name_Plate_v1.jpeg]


## Platform
